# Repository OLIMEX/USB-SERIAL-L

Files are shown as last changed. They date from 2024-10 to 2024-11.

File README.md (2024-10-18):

# USB-SERIAL-L
USB-SERIA-L is the ultimate Open Source Hardware USB to Serial converter with ful modem signals, supporting serial speeds from 100bps up to 3Mbps and with adjustable voltage levels from 0.65V up to 5V

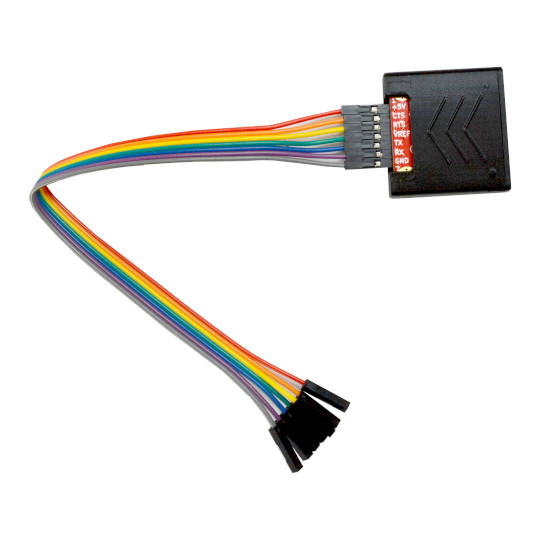
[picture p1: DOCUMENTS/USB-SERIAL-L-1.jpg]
USB-SERIAL-L


https://www.olimex.com/Products/USB-Modules/USB-SERIAL-L/

## Licensee
* Hardware is released under CERN Open Hardware Licence Version 2 - Strongly Reciprocal
* Software is released under GPL V3 Licensee
* Documentation is released under CC BY-SA 4.0

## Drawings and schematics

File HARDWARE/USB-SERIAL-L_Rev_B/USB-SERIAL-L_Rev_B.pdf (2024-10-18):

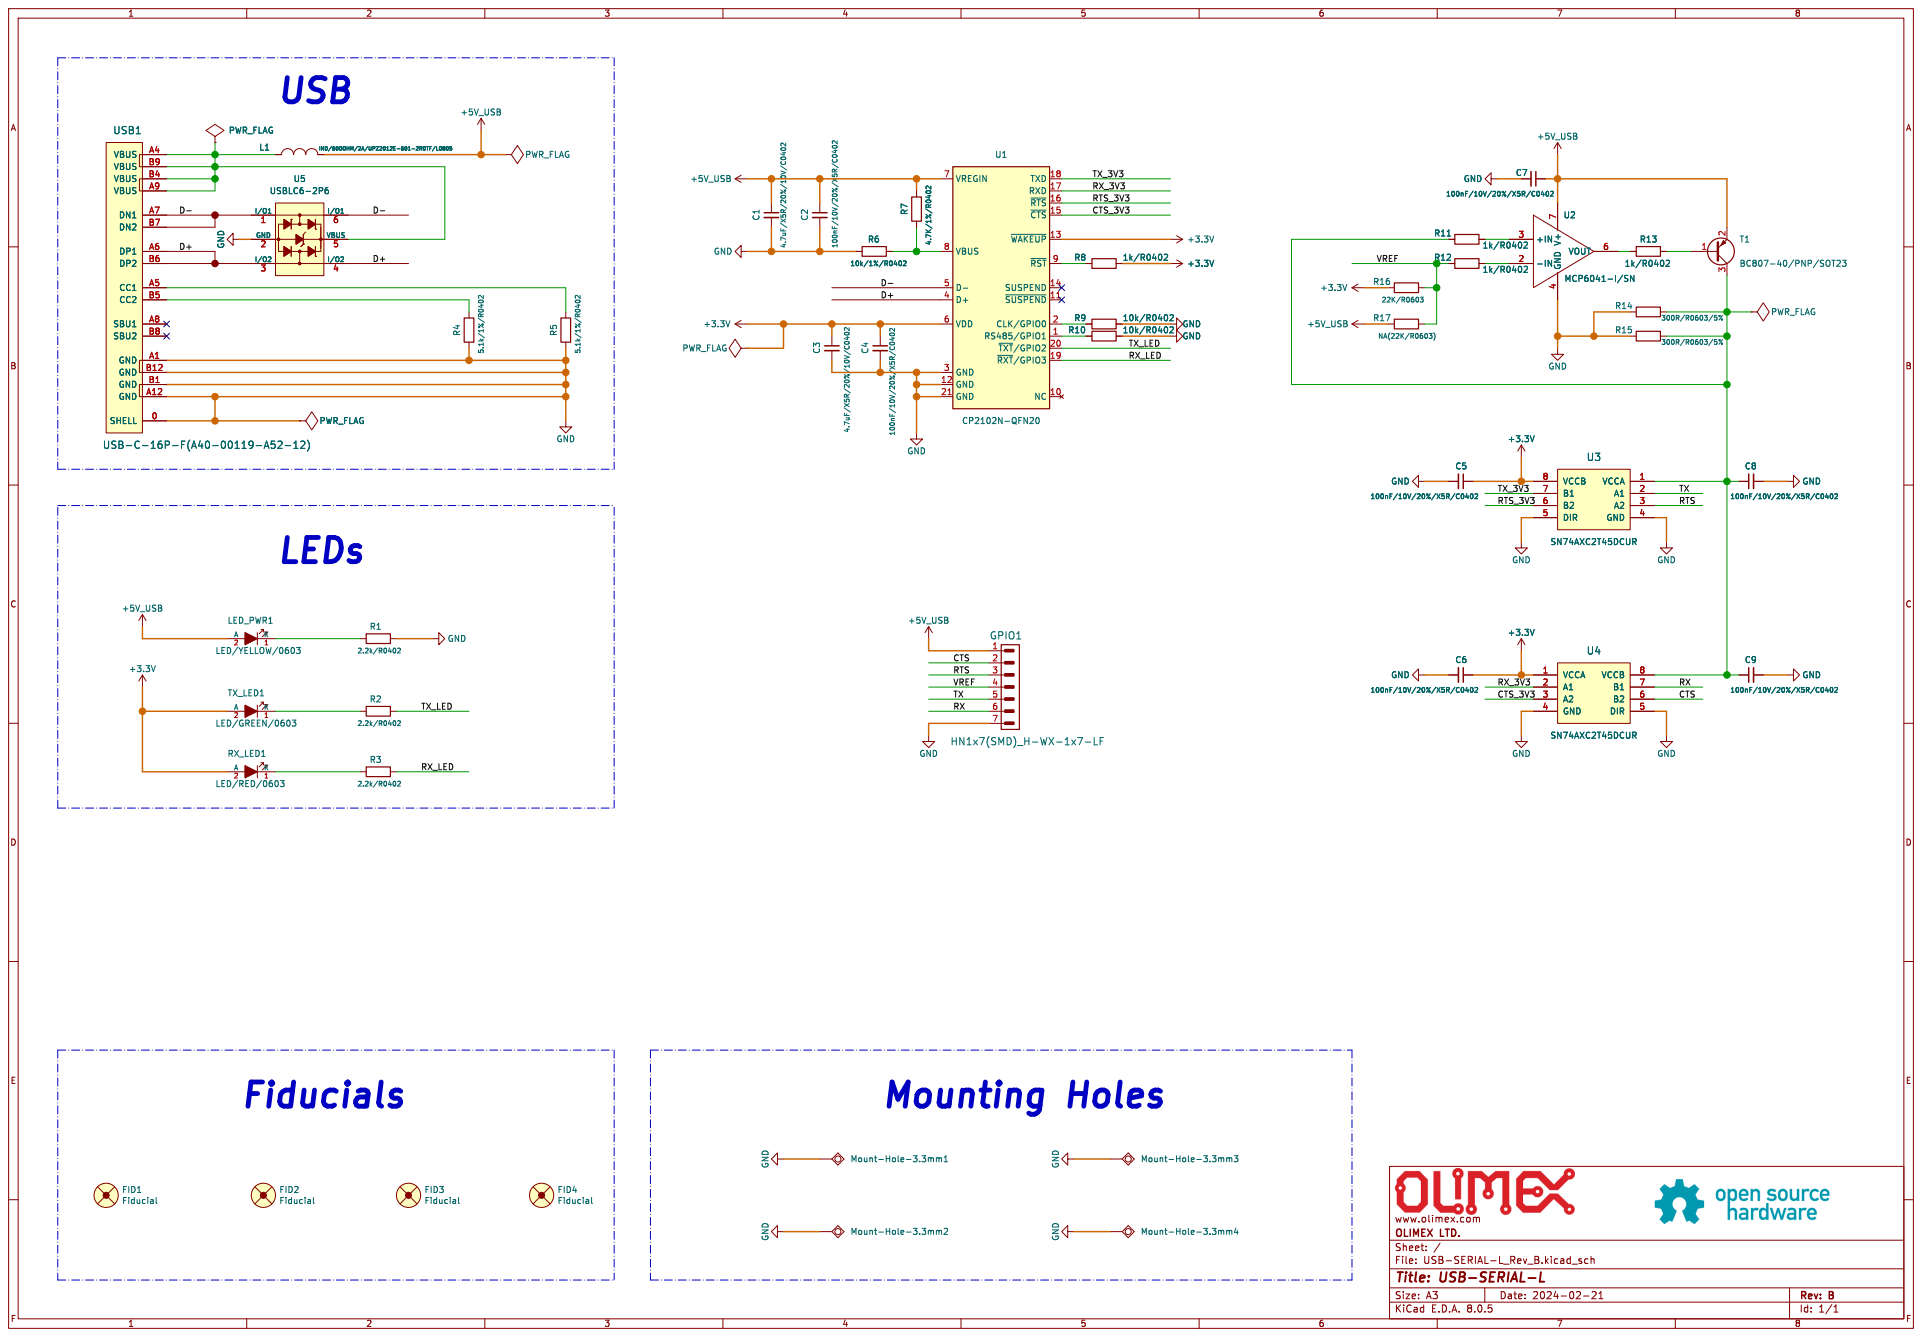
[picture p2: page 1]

2 3 T1BC807-40/PNP/SOT23 +3.3V VCCA 1 A1 2 A2 3 GND 4 DIR 5 B2 6 B1 7 VCCB 8 U4

Id: 1/1 Title: USB-SERIAL-L

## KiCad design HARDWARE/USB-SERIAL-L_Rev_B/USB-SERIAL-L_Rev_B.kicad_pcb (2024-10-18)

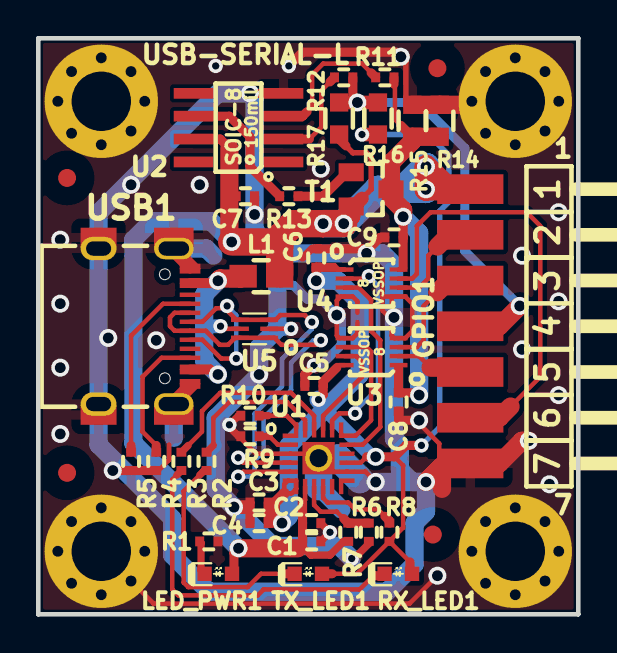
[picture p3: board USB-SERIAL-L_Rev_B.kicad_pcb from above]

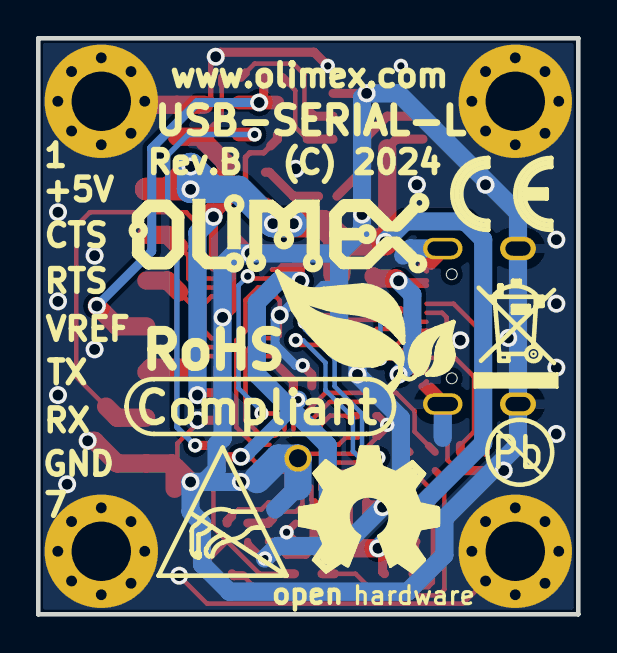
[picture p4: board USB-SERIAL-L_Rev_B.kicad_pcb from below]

Board: 2 copper layers, 30.0 x 32.0 mm, 53 parts (7 on the bottom side), 31 nets.

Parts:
C1, C3: 4.7uF/X5R/20%/10V/C0402; C_0402_5MIL_DWS
C2, C4, C5, C6, C7, C8, C9: 100nF/10V/20%/X5R/C0402; C_0402_5MIL_DWS
FID1, FID2: Fiducial; Fiducial1x3
FID3, FID4: Fiducial; Fiducial1x3_Paste
GPIO1: HN1x7(SMD)_H-WX-1x7-LF
L1: IND/600OHM/2A/UPZ2012E-601-2R0TF/L0805; L_0805_5MIL_DWS
LED_PWR1: LED/YELLOW/0603; LED_0603_KA
Logo_OLIMEX_TB-Bottom: Logo_OLIMEX_TB
Mount-Hole-3.3mm1, Mount-Hole-3.3mm2, Mount-Hole-3.3mm3, Mount-Hole-3.3mm4: Mounting_hole_Shield_3.3mm
R1, R2, R3: 2.2k/R0402; R_0402_5MIL_DWS
R4, R5: 5.1k/1%/R0402; R_0402_5MIL_DWS
R6: 10k/1%/R0402; R_0402_5MIL_DWS
R7: 4.7K/1%/R0402; R_0402_5MIL_DWS
R8, R11, R12, R13: 1k/R0402; R_0402_5MIL_DWS
R9, R10: 10k/R0402; R_0402_5MIL_DWS
R14, R15: 300R/R0603/5%; R_0603_5MIL_DWS
R16: 22K/R0603; R_0603_5MIL_DWS
R17: NA(22K/R0603); R_0603_5MIL_DWS
RX_LED1: LED/RED/0603; LED_0603_KA
Sign_Antistatic: Sign_Antistatic
Sign_CE: CE_Sign
Sign_OSHW_8x8: Sign_OSHW_8x8
Sign_PB-Free: Sign_PB-Free
Sign_RecycleBin: Sign_RecycleBin; Sign_RecycleBin_1
Sign_RoHS: Sign_RoHS; Sign_RoHS_1
T1: BC807-40/PNP/SOT23; SOT23
TX_LED1: LED/GREEN/0603; LED_0603_KA
U1: CP2102N-QFN20; QFN-20-1EP_3x3mm_P0.5mm_EP1.8x1.8mm
U2: MCP6041-I/SN; SOIC-8_150mil
U3, U4: SN74AXC2T45DCUR; VSSOP-8_Pitch-0.50mm_Pad-0.25mm_Dimensions-2.30x2.00x1.00mm
U5: USBLC6-2P6; SOT-666
USB1: USB-C-16P-F(A40-00119-A52-12); USB2.0_TYPE-C(A40-00119-A52-12)_Paste

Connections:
+3.3V: C3.1, C4.1, C5.1, C6.1, R8.2, R16.2, RX_LED1.2 (A), TX_LED1.2 (A), U1.6 (VDD), U1.13 (~WAKEUP), U3.8 (VCCB), U4.1 (VCCA)
+5V_USB: C1.1, C2.1, C7.1, GPIO1.1, L1.2, LED_PWR1.2 (A), R7.2, R17.2, T1.2 (E), U1.7 (VREGIN), U2.7 (V+)
/CTS: GPIO1.2, U4.6 (B2)
/CTS_3V3: U1.15 (~CTS), U4.3 (A2)
/D+: U1.4 (D+), U5.3 (I/O2), U5.4 (I/O2), USB1.A6 (DP1), USB1.B6 (DP2)
/D-: U1.5 (D-), U5.1 (I/O1), U5.6 (I/O1), USB1.A7 (DN1), USB1.B7 (DN2)
/RTS: GPIO1.3, U3.3 (A2)
/RTS_3V3: U1.16 (~RTS), U3.6 (B2)
/RX: GPIO1.6, U4.7 (B1)
/RX_3V3: U1.17 (RXD), U4.2 (A1)
/RX_LED: R3.2, U1.19 (~RXT/GPIO3)
/TX: GPIO1.5, U3.2 (A1)
/TX_3V3: U1.18 (TXD), U3.7 (B1)
/TX_LED: R2.2, U1.20 (~TXT/GPIO2)
/VREF: GPIO1.4, R12.1, R16.1, R17.1
GND: C1.2, C2.2, C3.2, C4.2, C5.2, C6.2, C7.2, C8.2, C9.2, GPIO1.7, Mount-Hole-3.3mm1.GND1, Mount-Hole-3.3mm2.GND1, Mount-Hole-3.3mm3.GND1, Mount-Hole-3.3mm4.GND1, R1.2, R4.1, R5.1, R6.2, R9.2, R10.2, R14.2, R15.2, U1.3 (GND), U1.12 (GND), U1.21 (GND), U2.4 (GND), U3.4 (GND), U3.5 (DIR), U4.4 (GND), U4.5 (DIR), U5.2 (GND), USB1.0 (SHELL), USB1.A1 (GND), USB1.A12 (GND), USB1.B1 (GND), USB1.B12 (GND)
unnamed: LED_PWR1.1 (K), R1.1
unnamed: R3.1, RX_LED1.1 (K)
unnamed: R13.2, T1.1 (B)
unnamed: C8.1, C9.1, R11.1, R14.1, R15.1, T1.3 (C), U3.1 (VCCA), U4.8 (VCCB)
unnamed: R2.1, TX_LED1.1 (K)
unnamed: R9.1, U1.2 (CLK/GPIO0)
unnamed: R10.1, U1.1 (RS485/GPIO1)
unnamed: R6.1, R7.1, U1.8 (VBUS)
unnamed: R8.1, U1.9 (~RST)
unnamed: R11.2, U2.3 (+IN)
unnamed: R12.2, U2.2 (-IN)
unnamed: R13.1, U2.6 (VOUT)
unnamed: L1.1, U5.5 (VBUS), USB1.A4 (VBUS), USB1.A9 (VBUS), USB1.B4 (VBUS), USB1.B9 (VBUS)
unnamed: R5.2, USB1.A5 (CC1)
unnamed: R4.2, USB1.B5 (CC2)

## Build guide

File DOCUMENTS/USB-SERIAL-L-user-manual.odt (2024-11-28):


USB-SERIAL-L

User Manual

Rev.1.1 November 2024 olimex.com

# What is USB-SERIAL-L

USB-SERIAL-L (https://www.olimex.com/Products/USB-Modules/USB-SERIAL-L/) is our most sophisticated USB to Serial convertor. It can work with any of our development boards as serial debug cable, or bootloader programmer for ESP32.

Compared to our other USB to SERIAL products it have two major advantages:

1. Speed - The high speed up to 3Mbps, for comparison USB-SERIAL-F can work only up to 1Mbps, BB-CH340T can work only up to 2Mbps.

2. Voltage levels - USB-SERIAL-L (https://www.olimex.com/Products/USB-Modules/USB-SERIAL-L/) can work with targets from 0.65V up to 5.5V. To adjust the voltage levels USB-SERIAL-L (https://www.olimex.com/Products/USB-Modules/USB-SERIAL-L/) have dedcated signal line Vref which has to be connected to target VCC. If this signal is left floating the voltage levels will be default to 3V.

3. Signals - USB-SERIAL-L (https://www.olimex.com/Products/USB-Modules/USB-SERIAL-L/) provide +5V from the USB to the target circuit.

The SERIAL interface has 4 signals Tx, Rx, RTS, CTS. Vref allow the voltage levels to be adjusted to these of the target.

USB-SERIAL-L (https://www.olimex.com/Products/USB-Modules/USB-SERIAL-L/) have nice 3D printed enclosure and comes with 200 mm long cables. The USB is connected with USB-C connector.

USB-SERIAL-L (https://www.olimex.com/Products/USB-Modules/USB-SERIAL-L/) provide 7 signals in this order +5V, CTS, RTS, Vref, Tx, Rx, GND.

# USB-SERIAL-L features:

- vaiable baud rate from 50bps up to 3Mbps
- output buffers with adjustable levels from 0.65 up to 5.5V
- Seven signal lines: +5V, GND, CTS, RTS, TX, RX, Vref
- provide +5V to the target from USB power
- Based on CP2102N from SiliconLabs and have drivers for Windows, Linux, Android, MacOS
- Three status LEDs: power, TX, RX
- Custom 3D printed plastic box
- Dimensions: 35 x 35 x 8 mm

# HARDWARE

## Schematic:

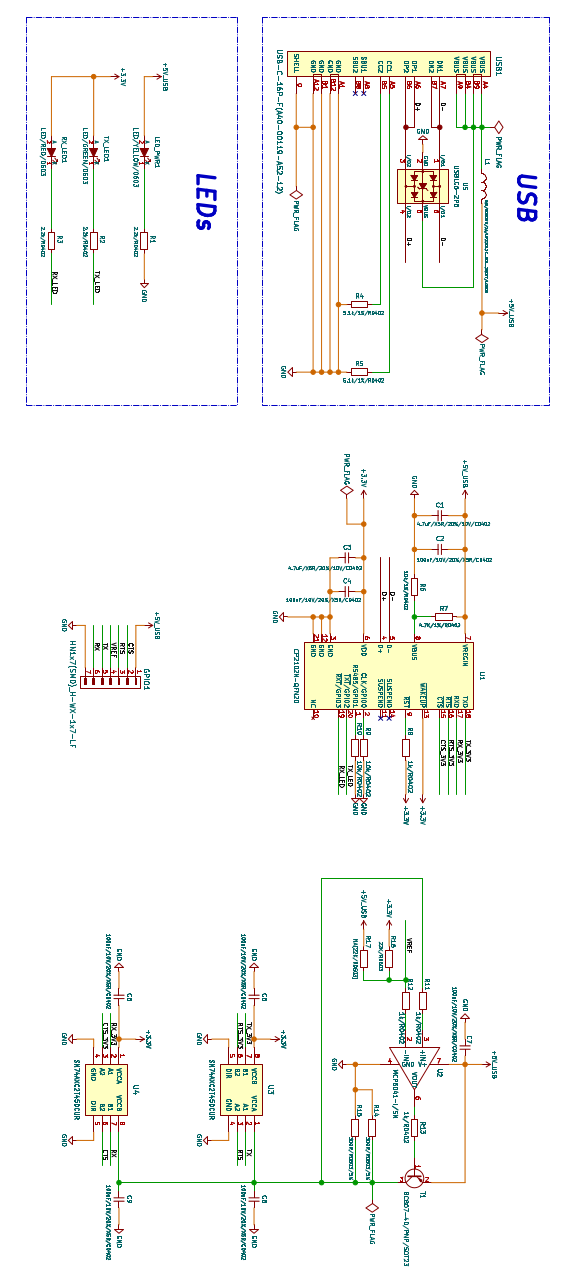
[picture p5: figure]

# SOFTWARE

Drivers for CP2102N can be download from here (https://www.silabs.com/developer-tools/usb-to-uart-bridge-vcp-drivers?tab=downloads).

Note that you have to install your drivers before you plug USB-SERIAL-L (https://www.olimex.com/Products/USB-Modules/USB-SERIAL-L/) to your computer.

# Order codes for USB-SERIAL-L

USB-SERIAL-L (https://www.olimex.com/Products/USB-Modules/USB-SERIAL-L/) USB2.0 to Serial converter with speed up to 3Mbps and adjustable voltage levels from 0.65V to 5.5V

# Revision History

Revision 1.0 October 2024

Revision 1.1 November 2024

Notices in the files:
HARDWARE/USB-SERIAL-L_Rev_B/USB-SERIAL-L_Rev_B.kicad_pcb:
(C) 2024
